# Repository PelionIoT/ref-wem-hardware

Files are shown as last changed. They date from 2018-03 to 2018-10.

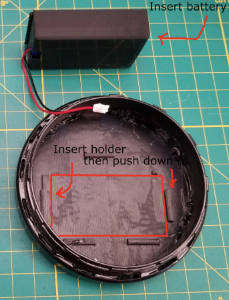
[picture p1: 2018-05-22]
images/image2017-12-12_13-3-46.png

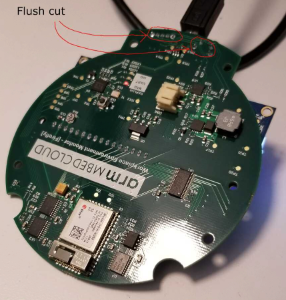
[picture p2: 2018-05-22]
images/image2017-12-12_12-34-34.png

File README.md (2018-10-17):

## Workplace Environmental Monitor Enclosure

This document contains information about the Workplace Environmental Monitor's:

- CAD - mechanical CAD and related files for the enclosure.
- Datasheets - component datasheets.
- PCB - PCB design files and outputs.

We provide these files under the Solderpad License v0.51.

We accept contributions to this project under the same license.

### Enclosure

Description: The PCB is a single board design. Test points are present for future test fixture and factory provisioning purposes. Enclosure parts are modular for more versatility and for less expensive and better printing. The locking mechanism is on the top half to allow inserting the PCB at assembly time. Enclosure parts include an exposed micro-USB connector, a sliding power switch, a charging LED and a button, all on the upper rim of the enclosure. Only the battery uses the bottom side of the enclosure. The light sensor has its own window to maximize response to environment changes. The temperature and humidity sensor is in a thermal relief area on the PCB and positioned directly under an air vent to make readings more accurate and more responsive. Light pipes join together to facilitate future press fit manufacturing. The enclosure uses locking clips and clamps throughout to eliminate the need for hot gluing during assembly.

#### Manufacturing choices

As currently designed, the top plate of the enclosure is meant to be printed with PolyJet technology. It has a very thin opaque layer on top, which makes the surface uniformly dark when powered off.
The remaining parts of the enclosure can be manufactured with any small-volume 3D printing technology - such as SLA, FDM or PolyJet.

If PolyJet is not available, a small modification to the top plate (removing the thin opaque layer to expose the light pipes all the way through) can make it printable with dual-material FDM. In this case, additional post-processing will be needed to get the same intended effect (completely opaque when powered off, but clearly showing the respective icon and/or light channel when the LED underneath is lit).

When printing, please ensure that the objects are oriented such that the outside surfaces come out smooth (polished), in order to minimize or even avoid the need for any post-processing.

For large volume manufacturing, the parts will require CAD modifications to accommodate whichever process is picked (e.g. wall drafting for injection molding, or separating the light pipes from the top plate for press fit). If you do any any such modifications, contributions to this repository are welcome.

#### Finishing choices

For our in-house production, we have used manual sanding and painting for the best results. Manufacturing houses all want to avoid this because of the high and nonscalable cost. Some houses offer automatic sanding and some mention the ability to paint, but without specific pricing. The recommendation is to manufacture the parts with no finish or with only automatic sanding, and determine whether the outcome is satisfactory.

#### Rendered images

<span class="images"></span>
<span class="images"></span>
<span class="images"></span>

#### Finished look

<span class="images"></span>
<span class="images"></span>
<span class="images"></span>
<span class="images"></span>
<span class="images"></span>

### Bringup

1. Connect power to the PCB, and switch it on. Increase the LCD contrast (knob labeled R16, located under the word "CLOUD" on the board) with a small Philips screwdriver, until you start seeing all white dots. Then, turn R16 in the opposite direction just until the dots disappear.
1. Plug in the board to a USB port. Make sure it enumerates as `CRP DISABLD`. On a Mac, this is under `/Volumes`.
1. Run this command: `rm /Volumes/CRP\ DISABLD/*; cp -X lpc11u35_mbed_cloud_connect_if_crc.bin /Volumes/CRP\ DISABLD/`
1. Wait for DAPLink to be flashed (depending on your machine, between 7 and ~70 seconds).
1. Turn the board off and then back on. Make sure it now enumerates as `DAPLINK`. If it still enumerates as before, you didn't wait long enough - go back to step 2.
1. Hold the reset button down. While keeping it down, run this command: `touch /Volumes/DAPLINK/auto_rst.cfg`
1. Let go of the reset button. 
1. Wait for the board to reboot.
1. Flash the firmware.

### Assembly

1. Flush cut the leads at the edge of the PCB, so they fit under the enclosure rim.<br>
    <span class="images">Leads</span>
1. Sand the light pipes to make them diffuse.
1. Fill out the inside of the cloud icon with black marker or paint to prevent the LED from shining through. Make sure you do not cross the cloud edge (where the light pipe is).
1. Remove the left half of the bottom clip to help the PCB go in easier.<br>
    <span class="images">Remove</span>
1. Assemble the top plate with the upper ring, so the USB hole is at the bottom (below the LCD cutout). Push the pins down gently with a tool. Don't push the ring itself, or the pins could break. Make sure the plate is flush with the ring and no gaps are showing. Optionally, hot glue the pins in place to provide more durability.
1. Insert light guides (don't glue them), and adjust the top of the marked tab to be an even height.
1. Using a dab of glue (hot glue), put the tiny cylindrical light pipe in.<br>
  <span class="images">Glue</span>
1. Assemble the bottom plate with the lower ring the same way as you assembled the top plate in step 5.
1. Place the battery in the battery holder, and assemble the holder onto the bottom plate.<br>
  <span class="images">Battery</span>
1. Remove the LCD's protective sheet, and insert the PCB into the top half of the enclosure. This is the trickiest step because the fit is tight. Align the connectors to the holes first, and then slide the PCB in and seat it into the guide. You have correctly inserted the PCB when there is no space between the LCD and the top plate of the enclosure. If possible, avoid putting fingerprints on the LCD.
1. Insert the two round PCB clips, and twist each of them 90 degrees clockwise to lock the PCB in place.<br>
  <span class="images">Clips</span>
1. Connect the battery to the PCB, and twist to lock the two enclosure halves. Test the basic functions, and ship it.<br>
  <span class="images">Connect</span>

#### LED order

|1|2|3|4|5|6|7|
|-|-|-|-|-|-|-|
|Power|Wi-fi|Cloud|Update/FOTA|Light sensor|Temperature and humidity sensor|LCD and future sound sensor

#### LED color state matrix

|LED name|In progress|Good|Bad|
|-|-|-|-|
|Power|Blink green|Green|Red
|Wi-Fi|Blink yellow|Blue|Red
|Cloud|Blink yellow|Blue|Red
|Firmware update (download in progress)|Blink yellow|Blue (on download completion)|Red
|Firmware update (perform verifications and write to flash)|Blue|Off (on flash completion, system rebooted) |Red

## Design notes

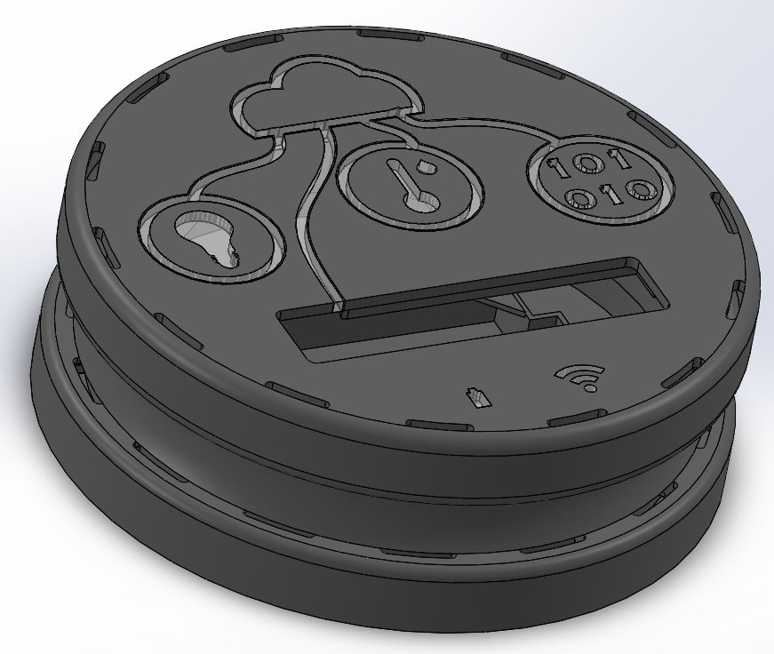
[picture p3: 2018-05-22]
images/earwig-02.png

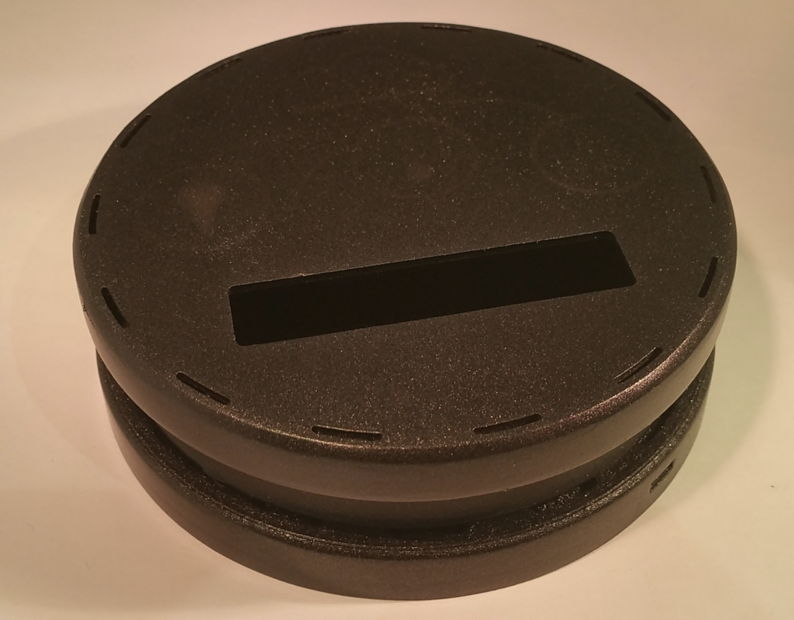
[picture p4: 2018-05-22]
images/earwig-08.png

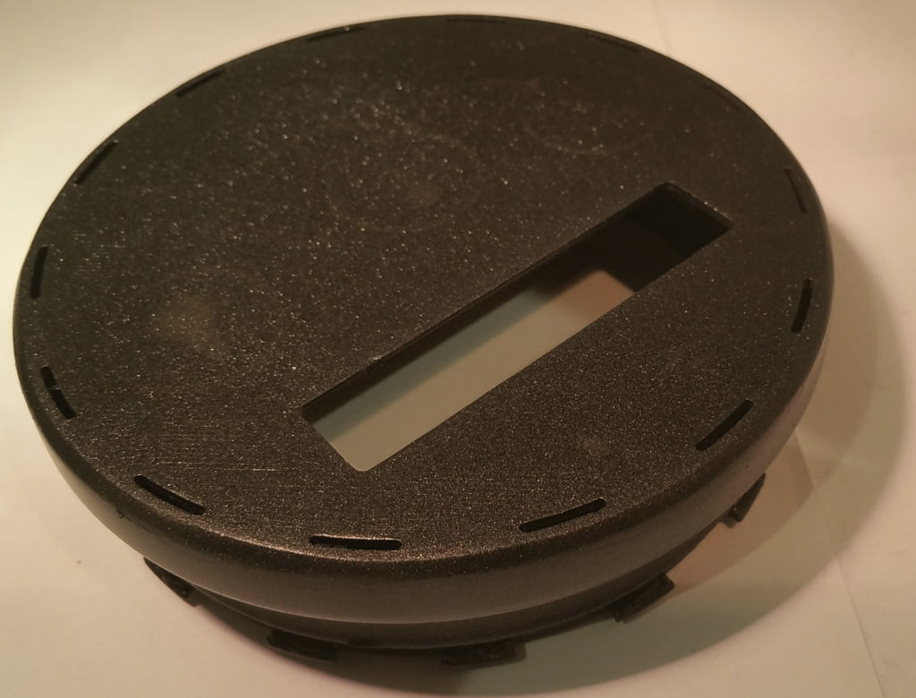
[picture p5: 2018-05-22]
images/earwig-06.png

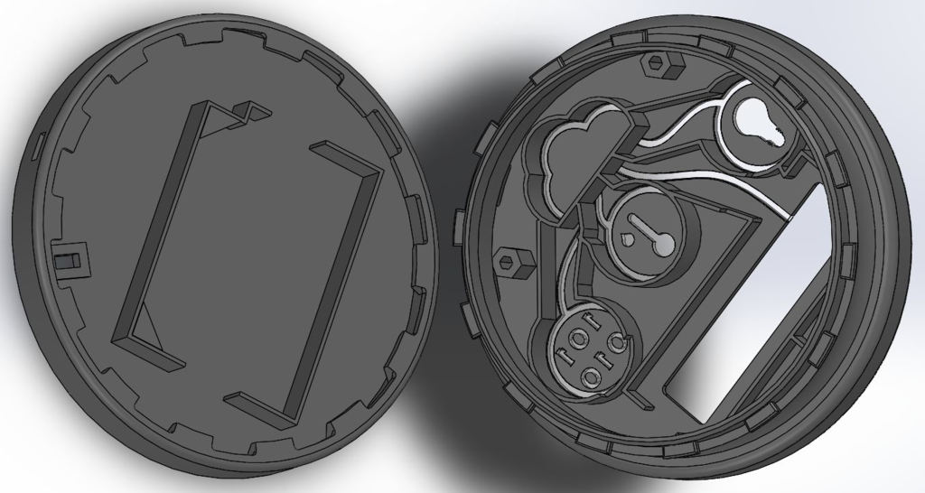
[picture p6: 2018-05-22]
images/earwig-03.png

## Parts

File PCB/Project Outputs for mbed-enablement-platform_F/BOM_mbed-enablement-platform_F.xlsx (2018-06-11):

Qty | Value | Device | Package | Parts | Description | MF | MFN | OC-DIGIKEY | OC-MOUSER | OC-NEWARK
1 | 10uF | CAPACITOR-POLARISEDB | SMC_B | C1 | Polarised capacitor | Kemet | T491B106K020AT | 399-8298-1-ND | 80-T491B106K020 | 57K1740
9 | 10uF | CAPACITOR0603 | 603 | C13, C14, C19, C21, C24, C27, C28, C29, C31 | Capacitor | Yageo | CC0603MRX5R5BB106 | 311-1448-1-ND | 603-CC603MRX5R5BB106 | 1458902
11 | 100nF | CAPACITOR0603 | 603 | C2, C3, C4, C8, C9, C10, C11, C12, C25, C26, C32 | Capacitor | AVX | 0603YC104KAT2A | 478-1239-1-ND | 581-060316C104K | 1327679
1 | 100uF | CAPACITOR-POLARISEDB | SMC_B | C30 | Polarised capacitor | AVX | F930J107MBA | 478-8156-1-ND | 647-F930J107MBA | 49H8755
4 | 18pF | CAPACITOR0402 | 402 | C5, C6, C15, C16 | Capacitor | Murata | GRM1555C1H180JA01D | 490-5858-1-ND | 81-GRM1555C1H180JA1D | 14T3293
6 | 100nF | CAPACITOR0402 | 402 | C7, C17, C18, C20, C22, C23 | Capacitor | AVX | 0402YD104KAT2A | 478-1126-1-ND | 581-0402YD104K | 1327666
1 | S2B-PH-SM4-TB(LF)(SN) | S2B-PH-SM4-TB(LF)(SN) | S2B-PH-SM4-TB(LF)(SN) | CON1 | 2 Position 2 mm JST PH Series Pitch Surface Mount Side Entry Shrouded Header | JST | S2B-PH-SM4-TB(LF)(SN) | 455-1749-1-ND |  | 38K8067
1 | 47346-0001 | 47346-0001 | USB-MICRO-B-H | CON2 | USB Receptacle Horizontal Micro Type B | MOLEX | 47346-0001 | WM17141CT-ND | 538-47346-0001 | 1568026
1 | BAT60A | BAT60A | SOD323 | D1 | SCHOTTKY DIODE | Infineon | BAT60AE6327HTSA1 | BAT60BE6327HTSA1CT-ND | 726-BAT60AE6327 | 85X4127
1 | BAT60J | BAT60J | SOD323 | D6 | SCHOTTKY DIODE | STMicroelectronics | BAT60JFILM | 497-3707-1-ND | 511-BAT60JFILM | 89K1218
1 | 6.8uH | INDUCTORNR8040T6R8N | NR8040T6R8N | L1 | Inductor | Taiyo Yuden | NR8040T6R8N | 587-2000-1-ND | 963-NR8040T6R8N
7 | CLP6C-FKB-CKNPRGJBB7A363 | CLP6C-FKB-CKNPRGJBB7A363 | 6-PLCC | LED1, LED2, LED3, LED4, LED5, LED6, LED7 | LED RGB SMD Diffused | Cree Inc. | CLP6C-FKB-CKNPRGJBB7A363 | CLP6C-FKB-CKNPRGJBB7A363CT-ND | 941-P6CFKBCKNPRGJ7A3 | 11X6459
1 | RED | SMD_LED0603 | CHIPLED_0603 | LED21 | LED SMD, Colour Red | Wurth Electronics Inc | 150060RS75000 | 732-4978-1-ND | 710-150060RS75000 | 2322071
1 | BLUE | SMD_LED0603 | CHIPLED_0603 | LED22 | LED SMD, Colour Blue | Wurth Electronics Inc | 150060BS75000 | 732-4966-1-ND | 710-150060BS75000 | 2322069
1 | GREEN | SMD_LED0603 | CHIPLED_0603 | LED23 | LED SMD, Colour Green | Wurth Electronics Inc | 150060GS75000 | 732-4971-1-ND | 710-150060GS75000 | 2322070
1 | SM1204BC-A/G | SM1204BC-A/G | CHIPLED_1204 | LED8 | Dual Colour LED SMD Right Angle, Colour Amber/Green | Bivar | SM1204BC-A/G | 492-1229-1-ND | 749-SM1204BC-A/G | 1814269
1 | 0 | RESISTOR0402 | 402 | R1 | Resistor | Yageo | RC0402JR-070RL | 311-0.0JRCT-ND | 603-RC0402JR-070RL | 603-RC0402JR-070RL
1 | 470R | RESISTOR0402 | 402 | R11 | Resistor | Vishay | CRCW0402470RJNED | 541-470JCT-ND | 71-CRCW0402J-470-E3 | 59M6737
1 | 10K | POTENTIOMETER | TC33X-2-103E | R16 | TRIMMER 10K OHM 0.1W SMD | Bourns Inc. | TC33X-2-103E | TC33X-103ECT-ND | 652-TC33X-2-103E | 97M3836
2 | 1.87M | RESISTOR0402 | 402 | R17, R20 | Resistor | Vishay | CRCW04021M87FKED | 541-1.87MLCT-ND | 71-CRCW04021M91FKED | 2141071
1 | 340K | RESISTOR0402 | 402 | R18 | Resistor | Yageo | RC0402FR-07340KL | YAG3121CT-ND | 603-RC0402FR-07340KL
9 | 10K | RESISTOR0402 | 402 | R2, R5, R9, R10, R15, R19, R29, R30, R31 | Resistor | Vishay | CRCW040210K0JNED | 541-10KJCT-ND | 652-CR0402-JW-103GLF | 59M6696
1 | 200K | RESISTOR0402 | 402 | R21 | Resistor | Panasonic | ERJ-2RKF2003X | P200KLCT-ND | 667-ERJ-2RKF2003X | 2059185
3 | 100K | RESISTOR0402 | 402 | R22, R24, R26 | Resistor | Vishay | CRCW0402100KJNED | 541-100KJCT-ND | 71-CRCW0402J-100K-E3 | 1652738
1 | 2K | RESISTOR0402 | 402 | R23 | Resistor | Vishay | CRCW04022K00FKED | 541-2.00KLCT-ND | 71-CRCW0402-2.0K-E3 | 1469688
1 | 270K | RESISTOR0402 | 402 | R25 | Resistor | Panasonic | ERJ-2RKF2703X | P270KLCT-ND | 667-ERJ-2RKF2703X | 2302885
2 | 1.0K | RESISTOR0402 | 402 | R27, R28 | Resistor | Vishay | CRCW04021K00JNED | 541-1.0KJCT-ND | 603-RE0402FRE071KL | 96Y9052
1 | 3.3K | RESISTOR0402 | 402 | R3 | Resistor | Vishay | CRCW04023K30FKEDHP | 541-3.30KYCT-ND | 71-CRCW04023K30FKEDH | 1738856
2 | 33R | RESISTOR0402 | 402 | R4, R7 | Resistor | Vishay | CRCW040233R0JNED | 541-33JCT-ND | 71-CRCW0402J-33-E3 | 72M6782
3 | 1.5K | RESISTOR0402 | 402 | R8, R12, R13 | Resistor | Panasonic | ERJ-2RKF1501X | 541-2889-1-ND | 791-RMC1/16SK152FTH | 2302656
1 | SKRKAEE010 | SKRKAEE010 | SKRKAEE010 | RESET | MOMENTARY SWITCH PUSH VERTICAL (SPST) | ALPS | SKRKAEE010 | CKN10506CT-ND | 688-SKRKAE
1 | OS102011MA1QN1 | OS102011MA1QN1 | OS102011MA1QN1 | SW1 | SWITCH SLIDE SPDT 100MA 12V | C&K Components | OS102011MA1QN1 | CKN9559-ND | 611-OS102011MA1QN1
1 | EVQ-PF006K | EVQ-PF006K | EVQ-PF006K | SW2 | MOMENTARY SWITCH RA (SPST) | Panasonic | EVQ-PF006K | P10879S-ND | 667-EVQ-PF006K
1 | BSS84 | BSS84 | SOT23-3 | T1 | MOSFET P-CHANNEL | Fairchild Semiconductor | BSS84 | BSS84CT-ND | 512-BSS84 | 58K8770
1 | ODIN-W262 | ODIN-W262 | ODIN-88 | U1 | ODIN-W260: Host-based multiradio module with | U-Blox | ODIN-W262 | 672-1017-1-ND
1 | TSL25911FN | TSL25911FN | 6-WFDFN | U10 | Sensor Light Digital, High Dynamic Range, 6-WFDFN | ams | TSL25911FN | TSL25911FNCT-ND | 985-TSL25911FN | 09X0688
1 | PCA9956BTWY | PCA9956BTWY | HTSSOP38 | U11 | 24 CHANNEL PWM LED DRIVER, 65mA/Channel | NXP USA Inc. | PCA9956BTWY | 568-12502-1-ND | 771-PCA9956BTWY | 2759860
1 | 1528-1502-ND | 1528-1502-ND | LCD1602 | U12 | 16x2 Character LCD, HD44780, white on blue. | Tinsharp | TC1602A-09T | 1528-1502-ND | 485-181 | 53W5770
1 | TPS61090RSAR | TPS61090RSAR | QFN-16 | U14 | Boost Converter 2A Switch, 96% Efficient Boost | Texas Instruments | TPS61090RSAR | 296-15259-1-ND | 595-TPS61090RSAR | 73H4652
1 | MCP73871-2CCI/ML | MCP73871-2CCI/ML | QFN-20 | U15 | Lithium-Ion/Polymer Charger IC 4.2V (1000mA) | Microchip | MCP73871-2CCI/ML | MCP73871-2CCI/ML-ND | 579-MCP73871-2CCI/ML | 1642489
1 | MX25R3235FM1IH0 | MX25R3235FM1IH0 | SO8 | U2 | Serial Flash 32 Mb 80 Mhz | Macronix | MX25R3235FM1IH0 | 1092-1175-ND
1 | USBLC6-2SC6SC6 | USBLC6-2SC6SC6 | SOT23-6L | U3 | ESD USB Protection Bi-Directional | STMicroelectronics | USBLC6-2SC6 | 497-5235-1-ND | 511-USBLC6-2SC6 | 26M4748
1 | LPC11U35FHI33/501 | LPC11U35FHI33/501 | HVQFN33 | U4 | CMSIS-DAP Interface : 32-bit LPC11U00 ARM Cortex M3 RISC 64KB Flash 2.5V/3.3V 33-Pin HVQFN EP | NXP | LPC11U35FHI33/501 | 568-9586-ND | 771-LPC11U35FHI33501 | 2115658
1 | TL1963A-33DCYR | TL1963A-33DCYR | SOT223 | U5 | LDO Fixed Regulator 3.3v, 1.5A | Texas Instruments | TL1963A-33DCYR | 296-24897-1-ND | 595-TL1963A-33DCYR | 94T5083
3 | TXS0108EPWR | TXS0108EPWR | TSSOP-20 | U6, U7, U13 | 8-Bit Bi-directional, Level-Shifting, Voltage Translator | Texas Instruments | TXS0108EPWR | 296-23011-1-ND | 595-TXS0108EPWR | 05R8300
1 | SHT31-DIS-B | SHT31-DIS-B | 8-DFN | U9 | Temperature and Humidity Sensor I2C 2% 8DFN | Sensirion | SHT31-DIS-B | 1649-1011-1-ND | 403-SHT31-DIS-B | 2474218
1 | 7M-12.000MAAJ-T | 7M-12.000MAAJ-T | 3.2X.2.5 | Y1 | Crystal, TXC 12MHz ¬±30ppm 18pF | TXC | 7M-12.000MAAJ-T | 887-1121-1-ND | 717-7M-12.000MAAJ-T | 84R5706
1 | 3.7V 4400mAh |  |  |  | Lithium-Ion Battery Pack with protection circuit | Adafruit | 354 | 1528-1834-ND | 485-354

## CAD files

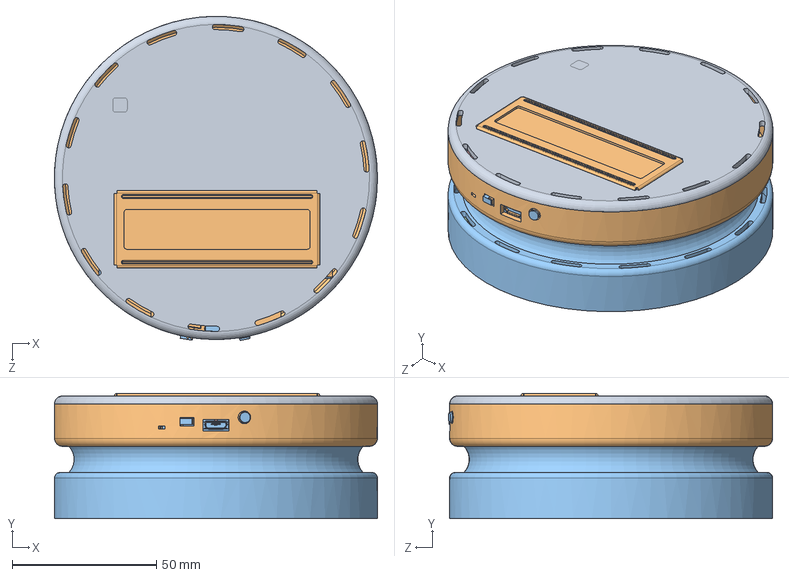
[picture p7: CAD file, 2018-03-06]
CAD/Enclosure Assembly.SLDASM
112.0 x 43.3 x 112.4 mm
Enclosure top plate
Enclosure middle upper
Enclosure middle lower
Enclosure bottom plate
Enclosure internal guides
Enclosure battery holder 18650x2
Enclosure light sensor tube
Enclosure PCB clips x 2
Enclosure slide clip

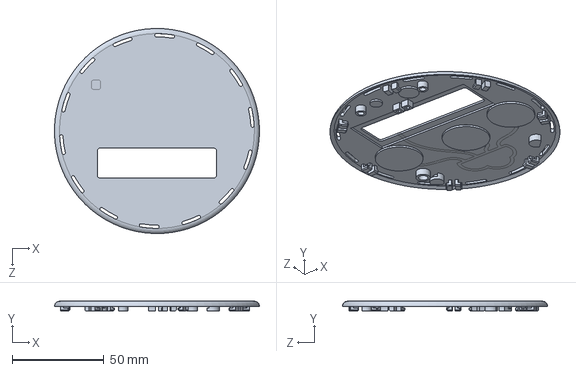
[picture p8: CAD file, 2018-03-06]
CAD/Enclosure top plate.SLDPRT
112.0 x 5.30 x 112.0 mm

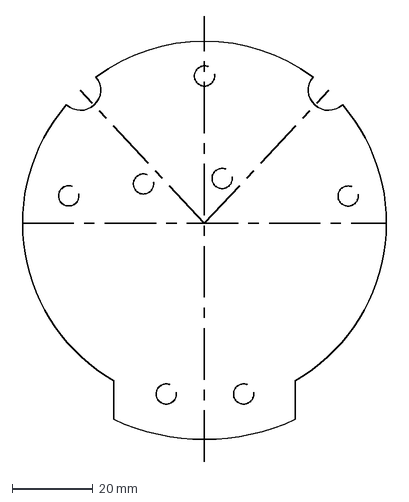
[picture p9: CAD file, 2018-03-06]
CAD/PCB area drawings/Single PCB outline.DXF
93.2 x 110.2 mm

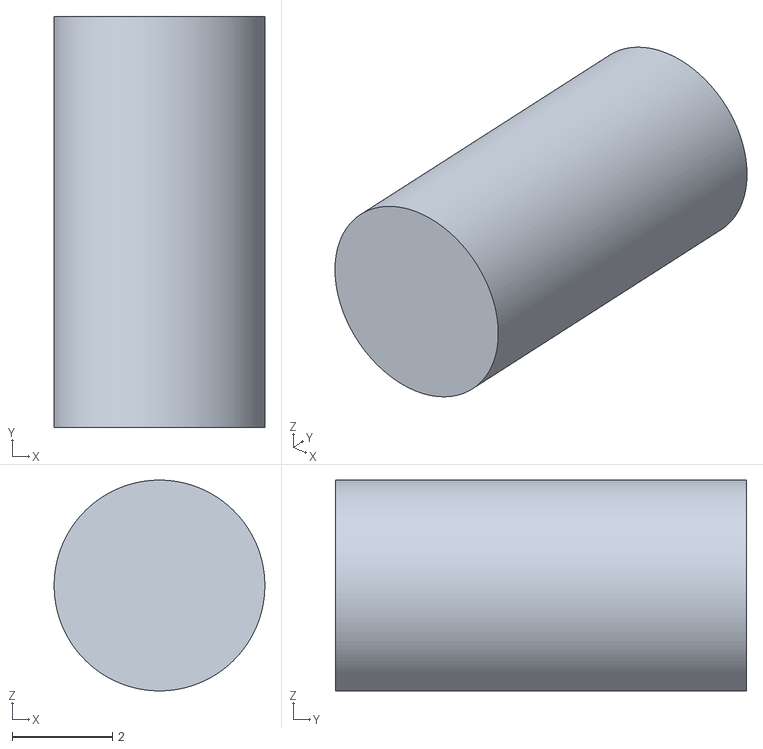
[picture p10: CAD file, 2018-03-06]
CAD/STL/Enclosure light sensor light pipe.stl
4.20 x 8.19 x 4.20

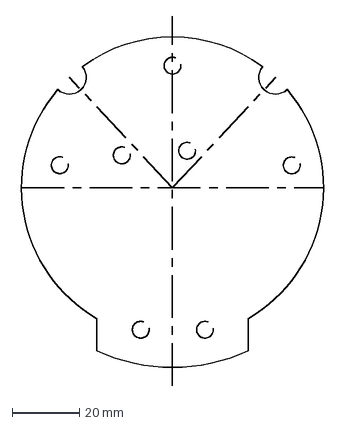
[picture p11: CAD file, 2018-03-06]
PCB/Single PCB outline.DXF
93.2 x 110.2 mm

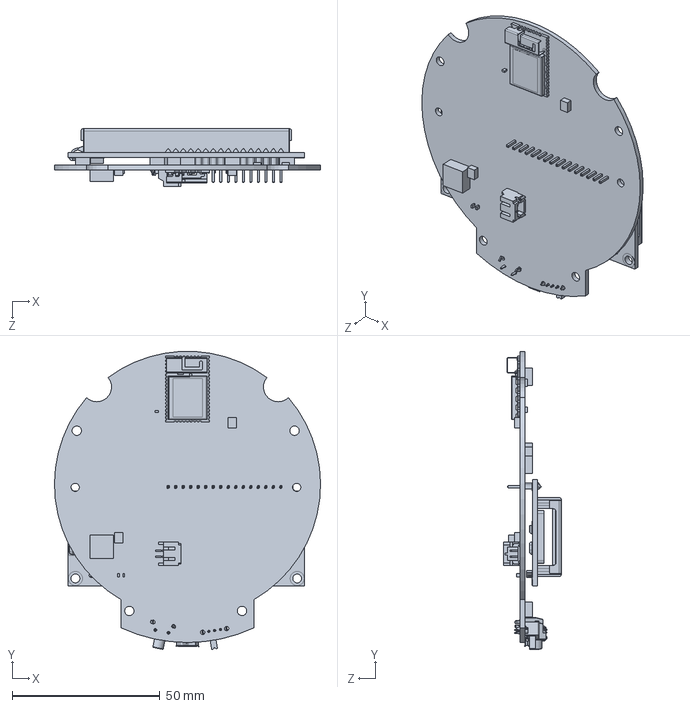
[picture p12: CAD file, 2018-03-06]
CAD/PCB area drawings/PCB 3D model.SLDPRT
90.0 x 100.8 x 19.5 mm

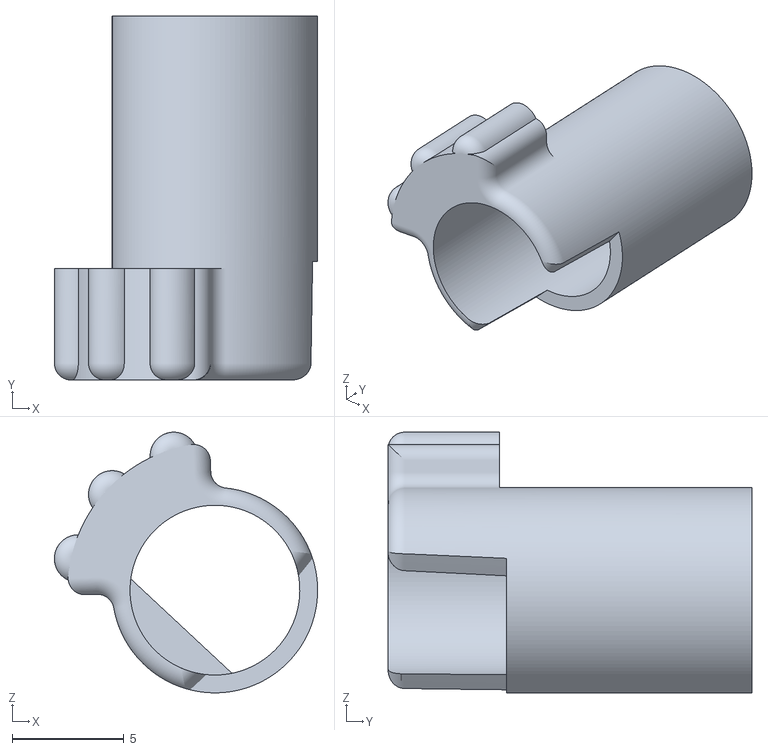
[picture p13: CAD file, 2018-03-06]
CAD/STL/Enclosure PCB clip.stl
11.8 x 16.3 x 11.7

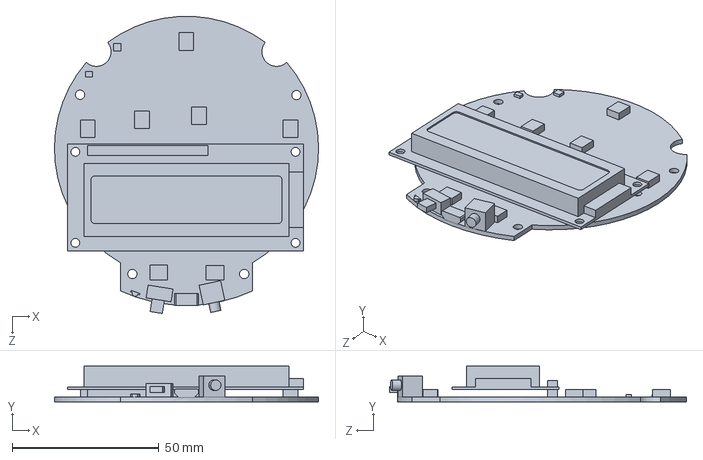
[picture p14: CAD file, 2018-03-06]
CAD/Enclosure PCB model.sldprt
90.0 x 12.1 x 101.2 mm

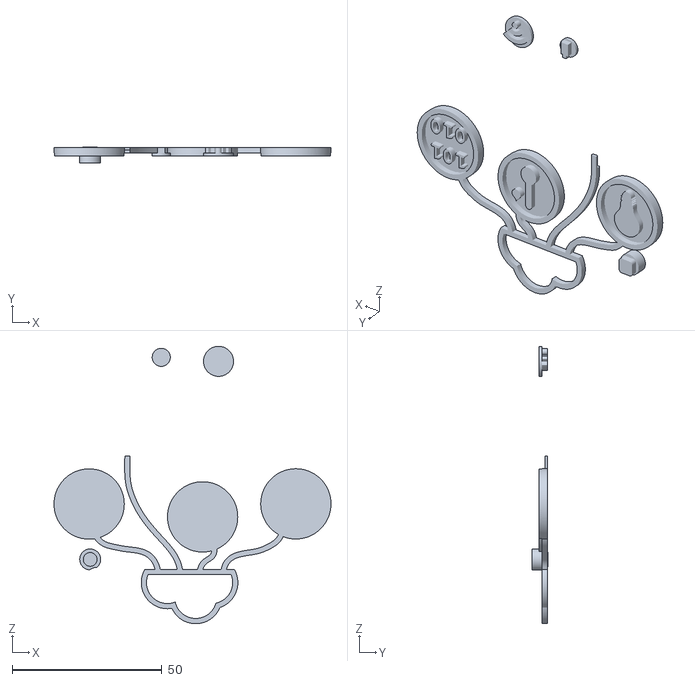
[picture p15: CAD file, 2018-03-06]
CAD/STL/Enclosure light pipes.stl
92.6 x 5.30 x 92.7

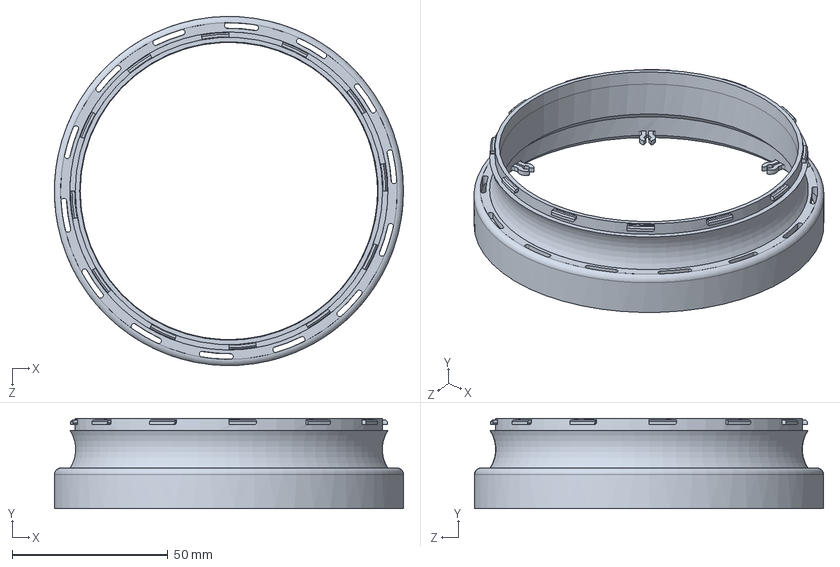
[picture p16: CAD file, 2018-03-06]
CAD/Enclosure middle lower.SLDPRT
112.0 x 28.9 x 112.0 mm

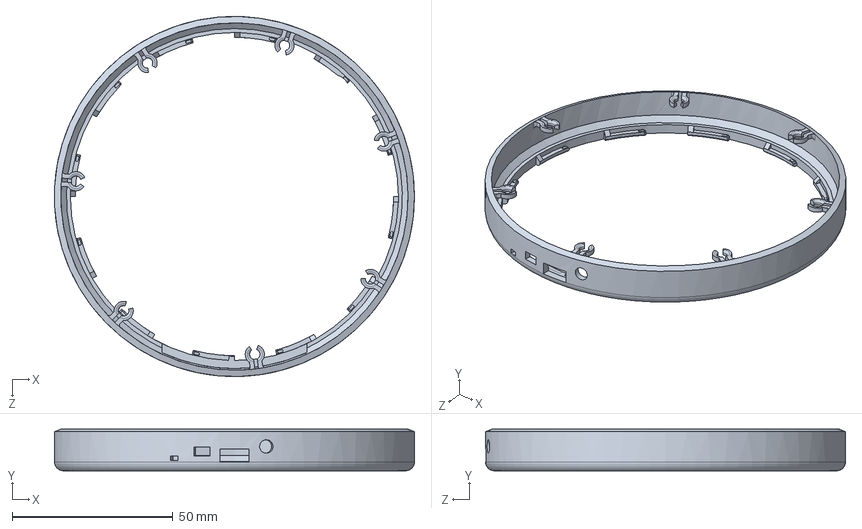
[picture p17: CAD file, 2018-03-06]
CAD/Enclosure middle upper.SLDPRT
112.0 x 13.0 x 112.0 mm

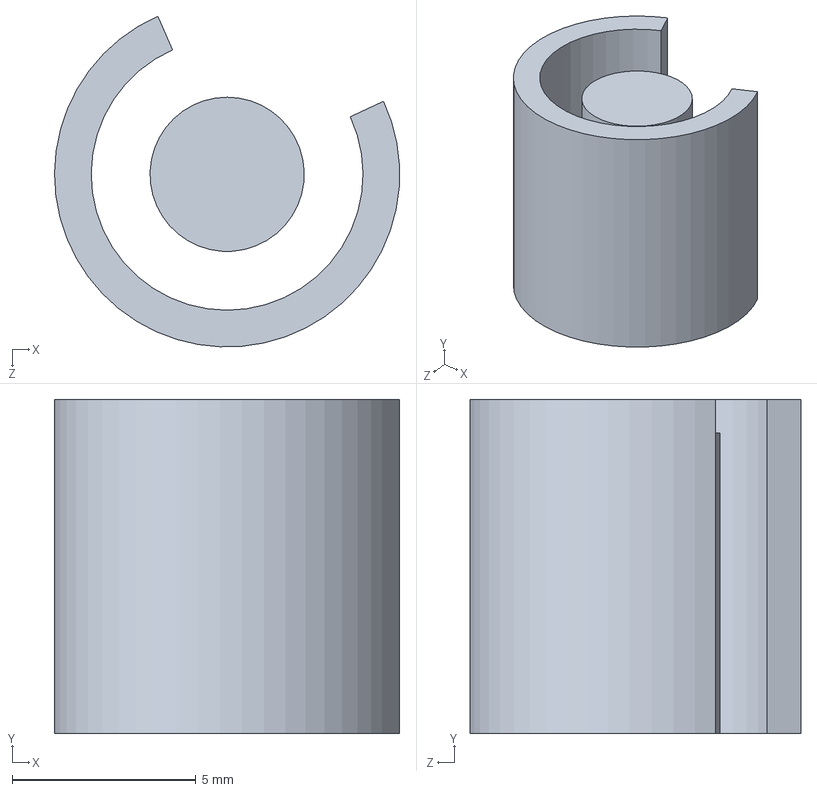
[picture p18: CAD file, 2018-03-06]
CAD/Enclosure light sensor tube.sldprt
9.39 x 9.10 x 9.00 mm

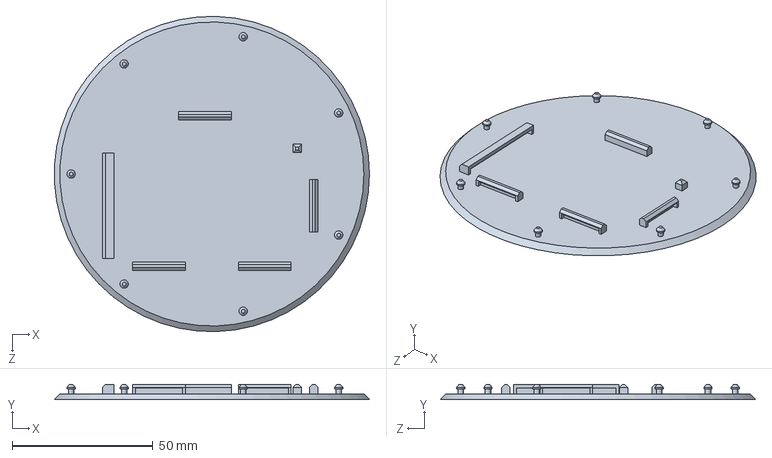
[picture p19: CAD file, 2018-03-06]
CAD/Enclosure bottom plate.SLDPRT
111.9 x 5.30 x 112.0 mm

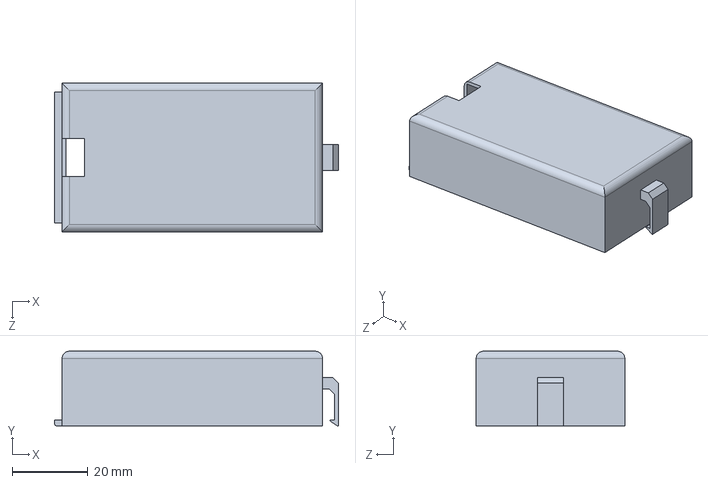
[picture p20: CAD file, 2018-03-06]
CAD/Enclosure battery holder 18650x2.sldprt
75.2 x 19.8 x 39.4 mm

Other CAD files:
CAD/Enclosure internal guides.sldprt
CAD/Enclosure battery holder LiPo flat 2500mAh.sldprt
CAD/Enclosure PCB clips.sldprt
CAD/Enclosure master.SLDPRT
CAD/Enclosure slide clip.sldprt
CAD/STL/Enclosure PCB model.stl
CAD/STL/Enclosure battery holder 18650x2.stl
CAD/STL/Enclosure bottom plate.stl
CAD/STL/Enclosure internal guides.stl
CAD/STL/Enclosure light sensor tube.stl
CAD/STL/Enclosure middle lower.stl
CAD/STL/Enclosure middle upper.stl
CAD/STL/Enclosure slide clip.stl
CAD/STL/Enclosure top plate.stl

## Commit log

2018-03-06 Initial commit for WEM
    This is the initial checkin of hardware files for the Workplace
    Environmental Monitor Reference Deployment.
    [BOM_mbed-enablement-platform_F.xlsx, Board_Stackup_mbed-enablement-platform_F.xls, Enclosure Assembly.SLDASM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]
2018-06-11 Add LiPo battery pack to BOM
    [BOM_mbed-enablement-platform_F.xlsx]
2018-06-20 Update manufacturing info
    Added details about current manufacturing choices and options.
